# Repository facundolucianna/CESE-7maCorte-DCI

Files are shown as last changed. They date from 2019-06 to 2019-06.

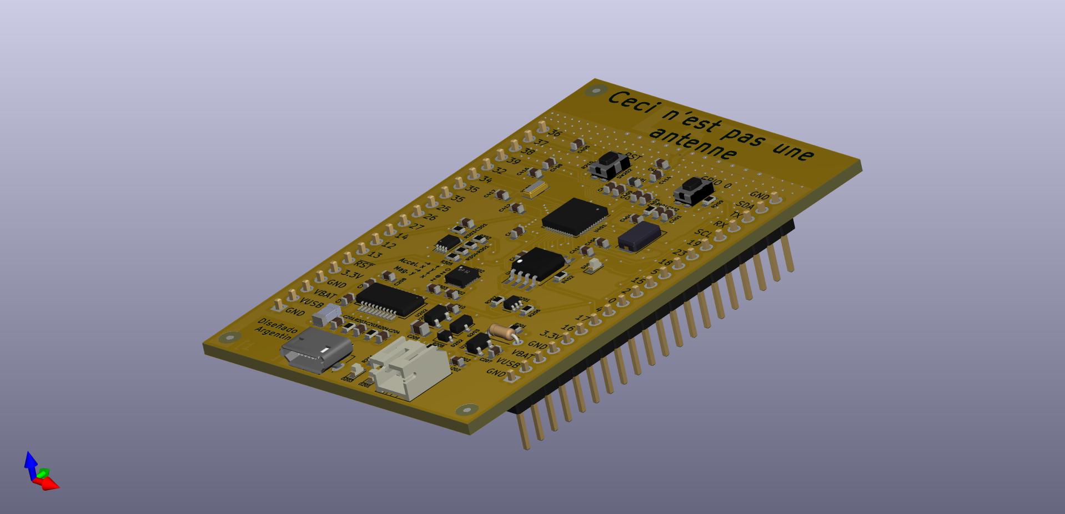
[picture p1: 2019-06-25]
3DPictures/13YellowWeirdAngle.jpg

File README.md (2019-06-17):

# CESE-7maCorte-DCI

Replica de Sparkfun ESP32 Thing. 

Basado de SparkFun ESP32 Thing (https://www.sparkfun.com/products/13907) 

Bajo Licencia Creative Commons Attributions Share-Alike 4.0 (https://creativecommons.org/licenses/by-sa/4.0/)

Modificación sin el respaldo del autor original

Atención:

Este diseño de PCB y esquematico se entrega "como está" y sin niguna garantia expresa o implícita, incluyendo, sin limitación, las garantias implícitas de comercialización y aptitude para un propósito particular.

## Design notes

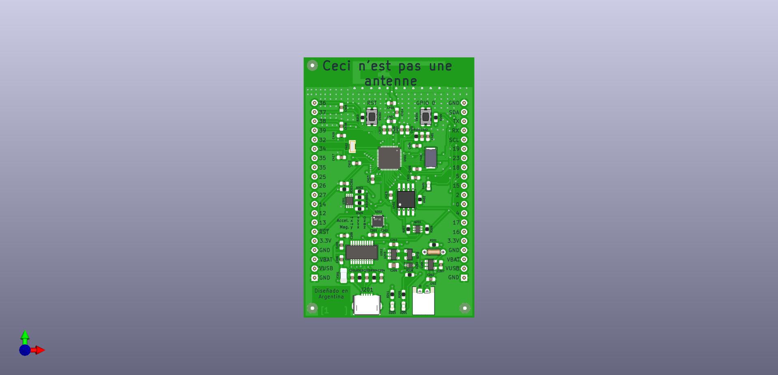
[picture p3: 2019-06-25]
3DPictures/07CheapVersionFront.jpg

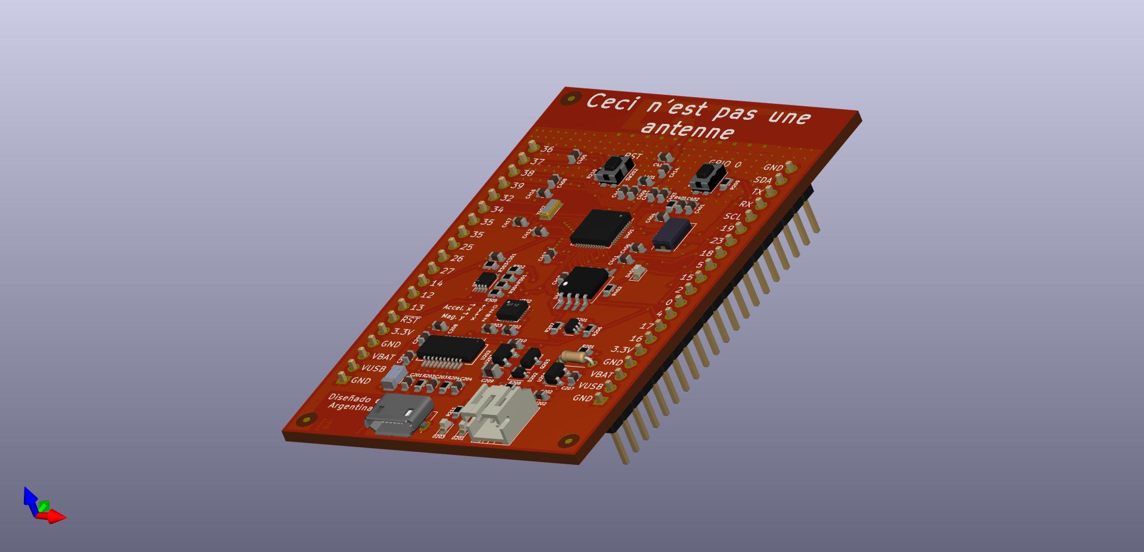
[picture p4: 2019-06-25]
3DPictures/11SparfunVersionWeirdAngle.jpg

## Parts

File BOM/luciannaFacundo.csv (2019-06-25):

Id | Designator | Package | Quantity | Designation | Supplier and ref
1 | A401 | SWRU120B | 1 | SWRU120B
2 | FID106,FID105,FID104,FID103,FID102,FID101 | Fiducial_1mm_Mask3mm | 6 | Fiducial
3 | U401 | QFN-48-1EP_6x6mm_P0.4mm_EP4.3x4.3mm | 1 | ESP32
4 | C210 | C_0603_1608Metric | 1 | 2.2uF
5 | Q203 | SOT-23 | 1 | 2.5A/30V
6 | Y402 | Crystal_SMD_3215-2Pin_3.2x1.5mm | 1 | 32.768kHz
7 | U301 | VSSOP-8_2.3x2mm_P0.5mm | 1 | PCA9306
8 | U203 | SOT-23-5 | 1 | AP2112K-3.3
9 | U202 | SSOP-20_3.9x8.7mm_P0.635mm | 1 | FT231XS
10 | U201 | SOT-23-5 | 1 | MCP73831
11 | SW202,SW201 | SW_Push_1P1T_NO_CK_KMR2 | 2 | SW_DIP_x01
12 | R402 | R_0603_1608Metric | 1 | 330
13 | R401 | R_0603_1608Metric | 1 | 20K
14 | R305,R304,R302,R301,R205 | R_0603_1608Metric | 5 | 1k
15 | R303 | R_0603_1608Metric | 1 | 200k
16 | R211 | R_0603_1608Metric | 1 | 1K
17 | R210,R209,R208,R207,R206 | R_0603_1608Metric | 5 | 10k
18 | R204,R203 | R_0603_1608Metric | 2 | 27
19 | R201 | R_0603_1608Metric | 1 | 2.0k
20 | Q201 | SOT-363_SC-70-6 | 1 | MBT3904DW1
21 | L401 | L_0603_1608Metric | 1 | 2.7nH
22 | JP401 | SolderJumper-3_P1.3mm_Bridged2Bar12_RoundedPad1.0x1.5mm | 1 | SolderJumper_3_Bridged12
23 | JP202,JP201 | SolderJumper-2_P1.3mm_Bridged2Bar_RoundedPad1.0x1.5mm | 2 | SolderJumper_2_Bridged
24 | J202 | JST_PH_S2B-PH-K_1x02_P2.00mm_Horizontal | 1 | LiPo
25 | F201 | Fuse_1206_3216Metric | 1 | 500mA
26 | D401 | LED_0603_1608Metric | 1 | BLUE
27 | D203 | LED_0603_1608Metric | 1 | RED
28 | D202 | D_SOD-323 | 1 | BAT20J
29 | D201 | LED_0603_1608Metric | 1 | YELLOW
30 | C418,C412,C411,C409,C407,C303,C302,C301,C208,C205,C201 | C_0603_1608Metric | 11 | 100nF
31 | C417,C416 | C_0603_1608Metric | 2 | 15pF
32 | C415 | C_0603_1608Metric | 1 | 2.4pF
33 | C414 | C_0603_1608Metric | 1 | 5.6pF
34 | C413 | C_0603_1608Metric | 1 | 1.0uF
35 | C410 | C_0603_1608Metric | 1 | 10uF
36 | C408,C405 | C_0603_1608Metric | 2 | 270pF
37 | C406,C404 | C_0603_1608Metric | 2 | 10pF
38 | C403 | C_0603_1608Metric | 1 | 100pF
39 | C402 | C_0603_1608Metric | 1 | 3nF
40 | C401 | C_0603_1608Metric | 1 | 10nF
41 | C209 | C_0805_2012Metric | 1 | 1.0uF
42 | C207,C206,C202 | C_0603_1608Metric | 3 | 4.7uF
43 | C204,C203 | C_0603_1608Metric | 2 | 47pF
44 | U402 | SOIC-8_5.23x5.23mm_P1.27mm | 1 | W25Q32JVSS
45 | J401,J402 | PinHeader_1x20_P2.54mm_Vertical | 2 | Conn_01x20
46 | U302 | InvenSense_QFN-24_3x3mm_P0.4mm | 1 | ICM-20948
47 | R202 | R_Axial_DIN0204_L3.6mm_D1.6mm_P5.08mm_Horizontal | 1 | DNP
48 | J201 | USB_Micro-B_GCT_USB3076-30-A | 1 | USB_B_Micro
49 | LOGO101 | OSHW-Logo2_7.3x6mm_SilkScreen | 1 | Logo_Open_Hardware
50 | LOGO102 | KiCad-Logo2_5mm_SilkScreen | 1 | Logo_Kicad
51 | Y401 | Crystal_SMD_5032-2Pin_5.0x3.2mm | 1 | 26MHz

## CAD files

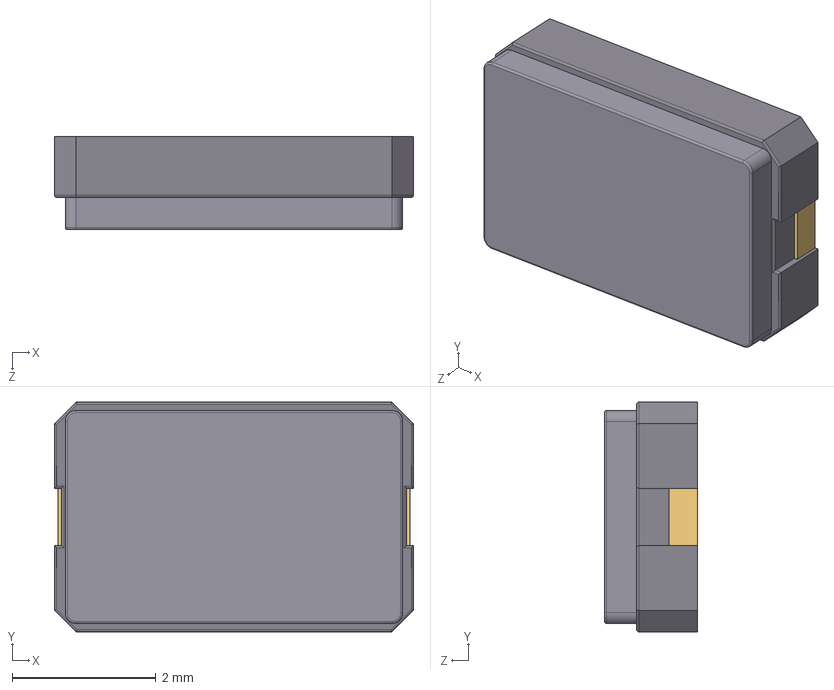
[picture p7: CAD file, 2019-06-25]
3dfootprints/User Library-ABM3-1.STEP
5.00 x 3.20 x 1.30 mm
User Library-ABM3-1_Fillet002
User Library-ABM3-1_Fillet001
User Library-ABM3-1_Pad001

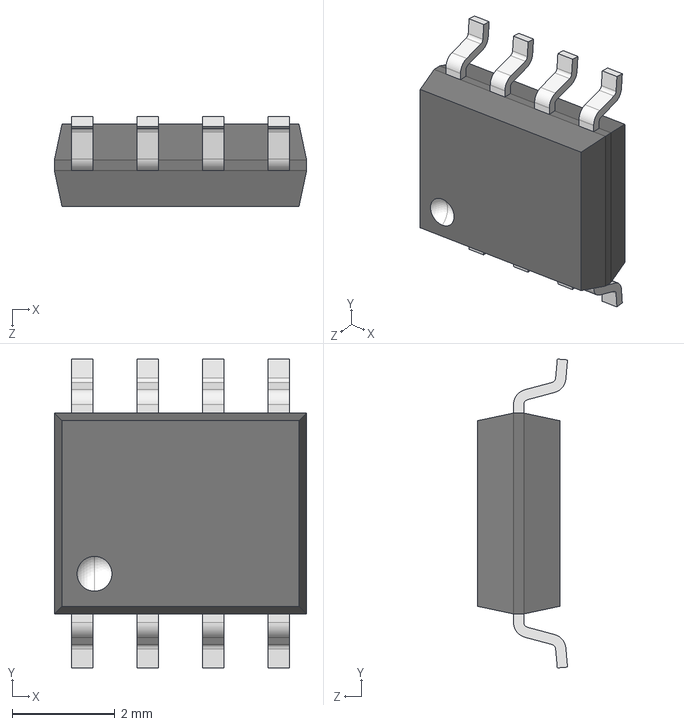
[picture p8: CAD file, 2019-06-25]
3dfootprints/User Library-SOIC-8-1.step
4.90 x 6.00 x 1.75 mm

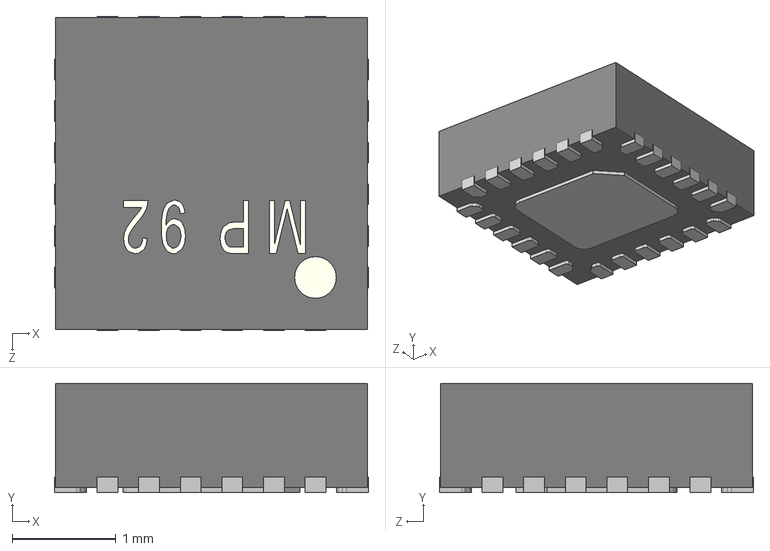
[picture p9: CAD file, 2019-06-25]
3dfootprints/User Library-MPU9250.step
3.02 x 1.05 x 3.02 mm

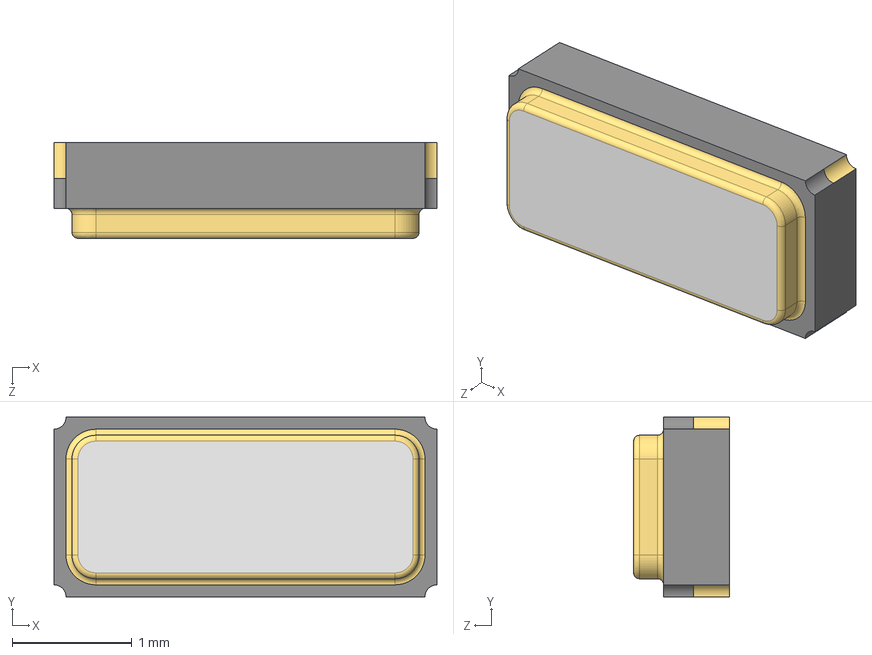
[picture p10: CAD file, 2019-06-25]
3dfootprints/User Library-NDK_NX3215SA.step
3.20 x 1.50 x 0.8 mm

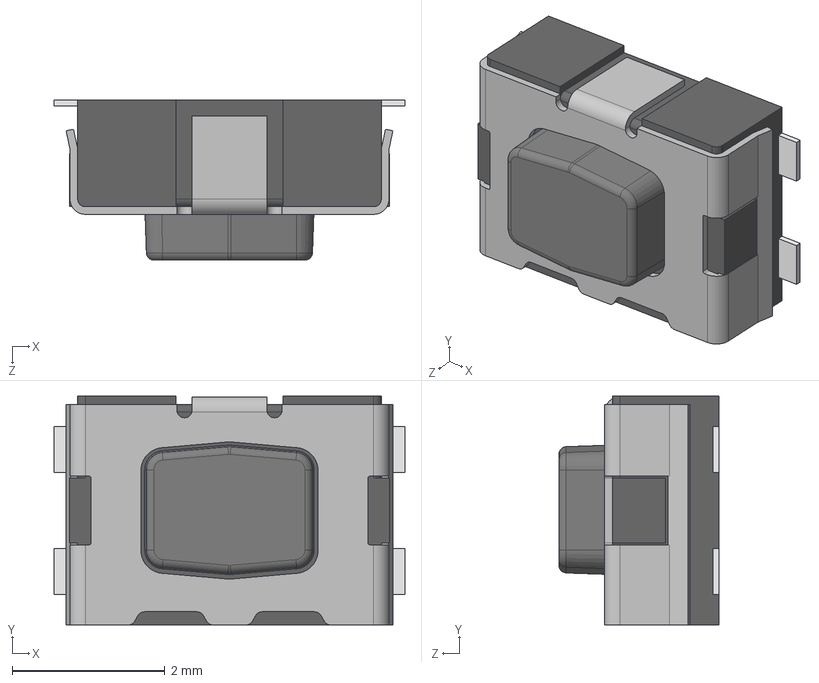
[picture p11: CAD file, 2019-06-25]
3dfootprints/User Library-Switch-CK-KMR2.STEP
4.60 x 3.00 x 2.10 mm
User Library-Switch-CK-KMR2_Button
User Library-Switch-CK-KMR2_Boitier
User Library-Switch-CK-KMR2_Tole
User Library-Switch-CK-KMR2_Pads

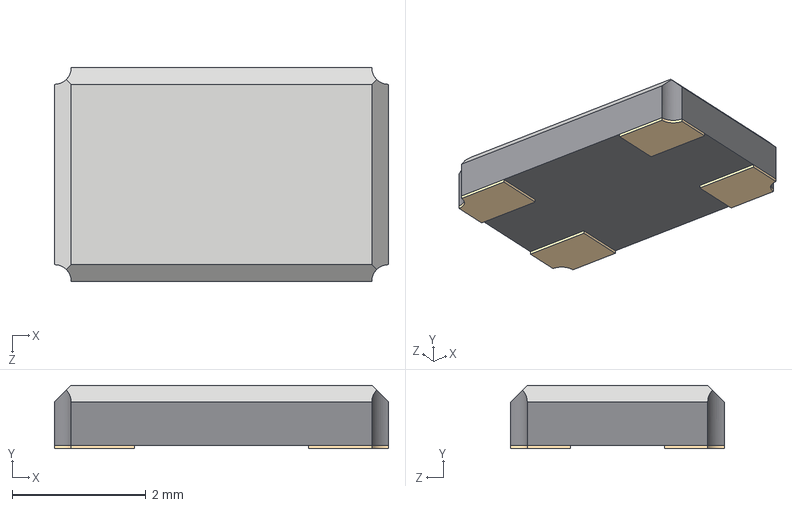
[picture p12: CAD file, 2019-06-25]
3dfootprints/User Library-Crystal.step
5.00 x 0.95 x 3.20 mm

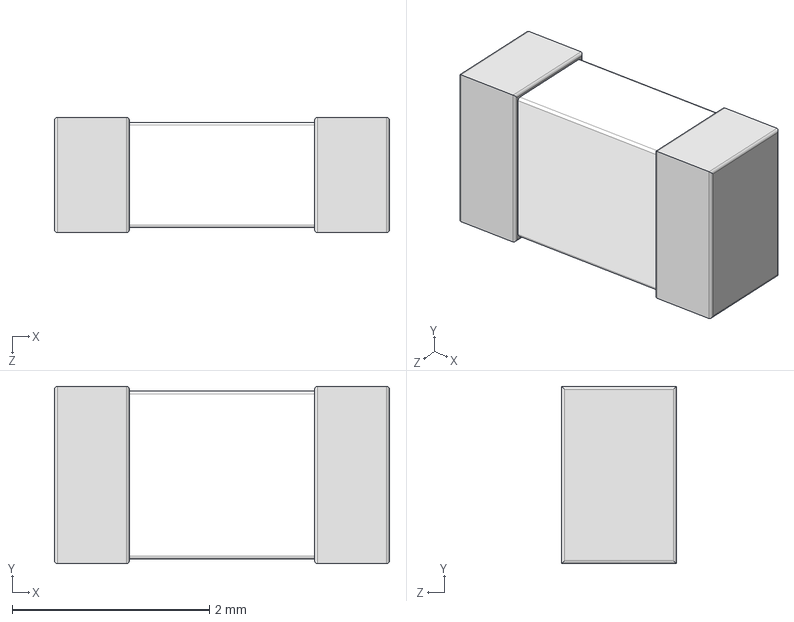
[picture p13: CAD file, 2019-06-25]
3dfootprints/User Library-Fuse_1206.step
3.40 x 1.80 x 1.17 mm

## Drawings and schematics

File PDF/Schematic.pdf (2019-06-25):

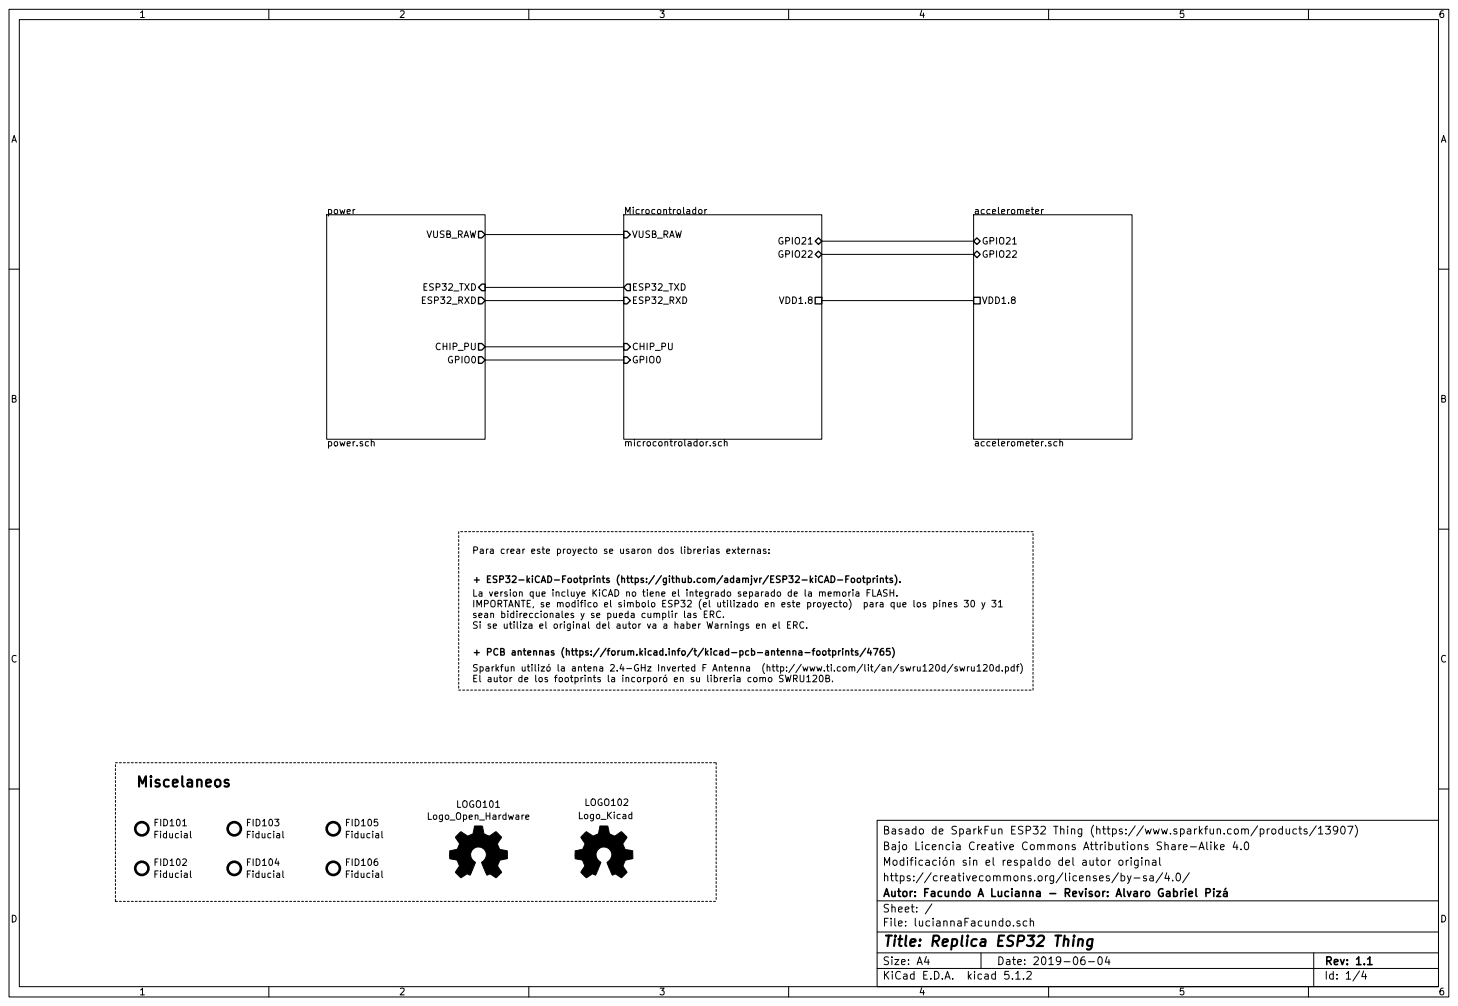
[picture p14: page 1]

accelerometer accelerometer.sch GPIO21 GPIO22 VDD1.8 Microcontrolador microcontrolador.sch CHIP_PU

+ ESP32-kiCAD-Footprints (https://github.com/adamjvr/ESP32-kiCAD-Footprints).
La version que incluye KiCAD no tiene el integrado separado de la memoria FLASH.
IMPORTANTE, se modifico el simbolo ESP32 (el utilizado en este proyecto) para que los pines 30 y 31
sean bidireccionales y se pueda cumplir las ERC.
Si se utiliza el original del autor va a haber Warnings en el ERC.

+ PCB antennas (https://forum.kicad.info/t/kicad-pcb-antenna-footprints/4765) FID104 Fiducial FID103 Fiducial FID101 Fiducial FID102 Fiducial Miscelaneos

Sparkfun utilizó la antena 2.4-GHz Inverted F Antenna (http://www.ti.com/lit/an/swru120d/swru120d.pdf)
El autor de los footprints la incorporó en su libreria como SWRU120B.

Basado de SparkFun ESP32 Thing (https://www.sparkfun.com/products/13907)
Bajo Licencia Creative Commons Attributions Share-Alike 4.0
Modificación sin el respaldo del autor original
https://creativecommons.org/licenses/by-sa/4.0/
File: luciannaFacundo.sch Sheet: / Autor: Facundo A Lucianna - Revisor: Alvaro Gabriel Pizá

Id: 1/4 Title: Replica ESP32 Thing

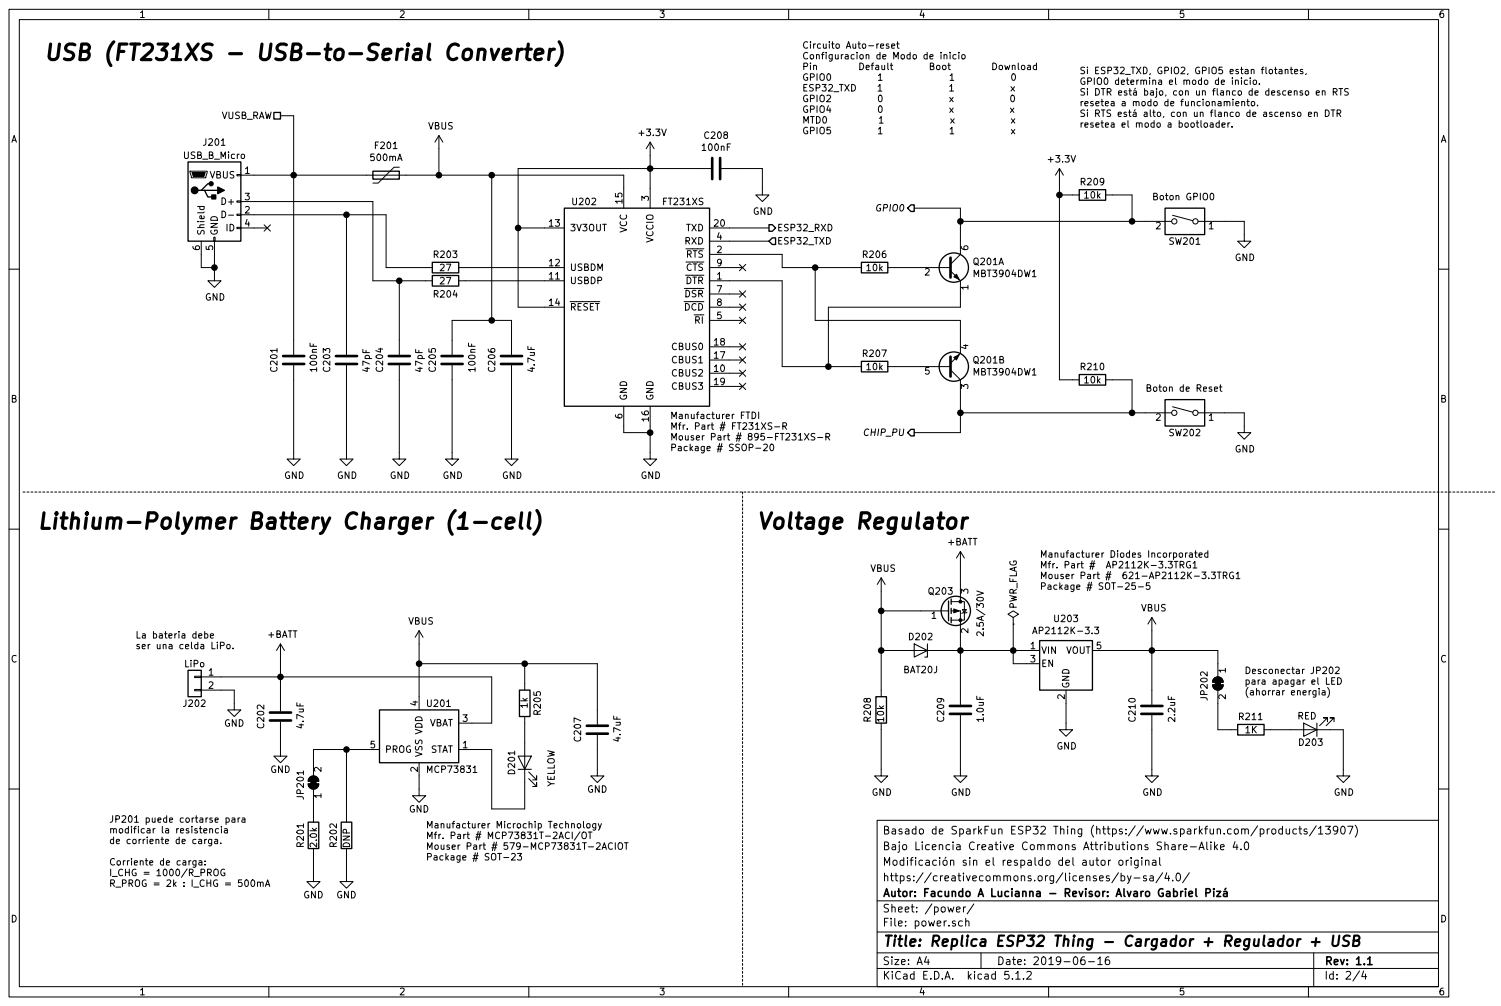
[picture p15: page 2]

USB (FT231XS - USB-to-Serial Converter)

10k Si ESP32_TXD, GPIO2, GPIO5 estan flotantes, GPIO0 determina el modo de inicio. Si DTR está bajo, con un flanco de descenso en RTS

resetea a modo de funcionamiento. Si RTS está alto, con un flanco de ascenso en DTR

Boton GPIO0 Boton de Reset 1
CHIP_PU GPIO0 R206

Manufacturer Diodes Incorporated Mfr. Part # AP2112K-3.3TRG1 Mouser Part # 621-AP2112K-3.3TRG1 Package # SOT-25-5

JP201 puede cortarse para modificar la resistencia

Manufacturer Microchip Technology Mfr. Part # MCP73831T-2ACI/OT Mouser Part # 579-MCP73831T-2ACIOT Package # SOT-23

Basado de SparkFun ESP32 Thing (https://www.sparkfun.com/products/13907)
Bajo Licencia Creative Commons Attributions Share-Alike 4.0
Modificación sin el respaldo del autor original
https://creativecommons.org/licenses/by-sa/4.0/
Autor: Facundo A Lucianna - Revisor: Alvaro Gabriel Pizá
Sheet: /power/
File: power.sch
Id: 2/4 Title: Replica ESP32 Thing - Cargador + Regulador + USB

de corriente de carga.

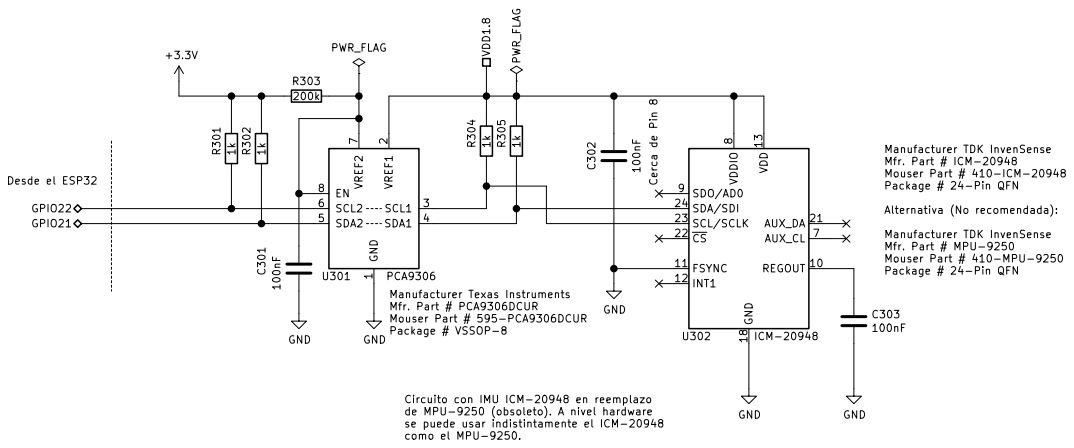
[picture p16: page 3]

7 EN 8U301 PCA9306 C301 100nF R304 1kR305 1k Cerca de Pin 8

Circuito con IMU ICM-20948 en reemplazo
de MPU-9250 (obsoleto). A nivel hardware
se puede usar indistintamente el ICM-20948

Modificación sin el respaldo del autor original
https://creativecommons.org/licenses/by-sa/4.0/
Modificacion: Agregado de IMU
Id: 3/4 Title: Replica ESP32 Thing - Inertial measurement unit File: accelerometer.sch Sheet: /accelerometer/ Autor: Facundo A Lucianna - Revisor: Alvaro Gabriel Pizá

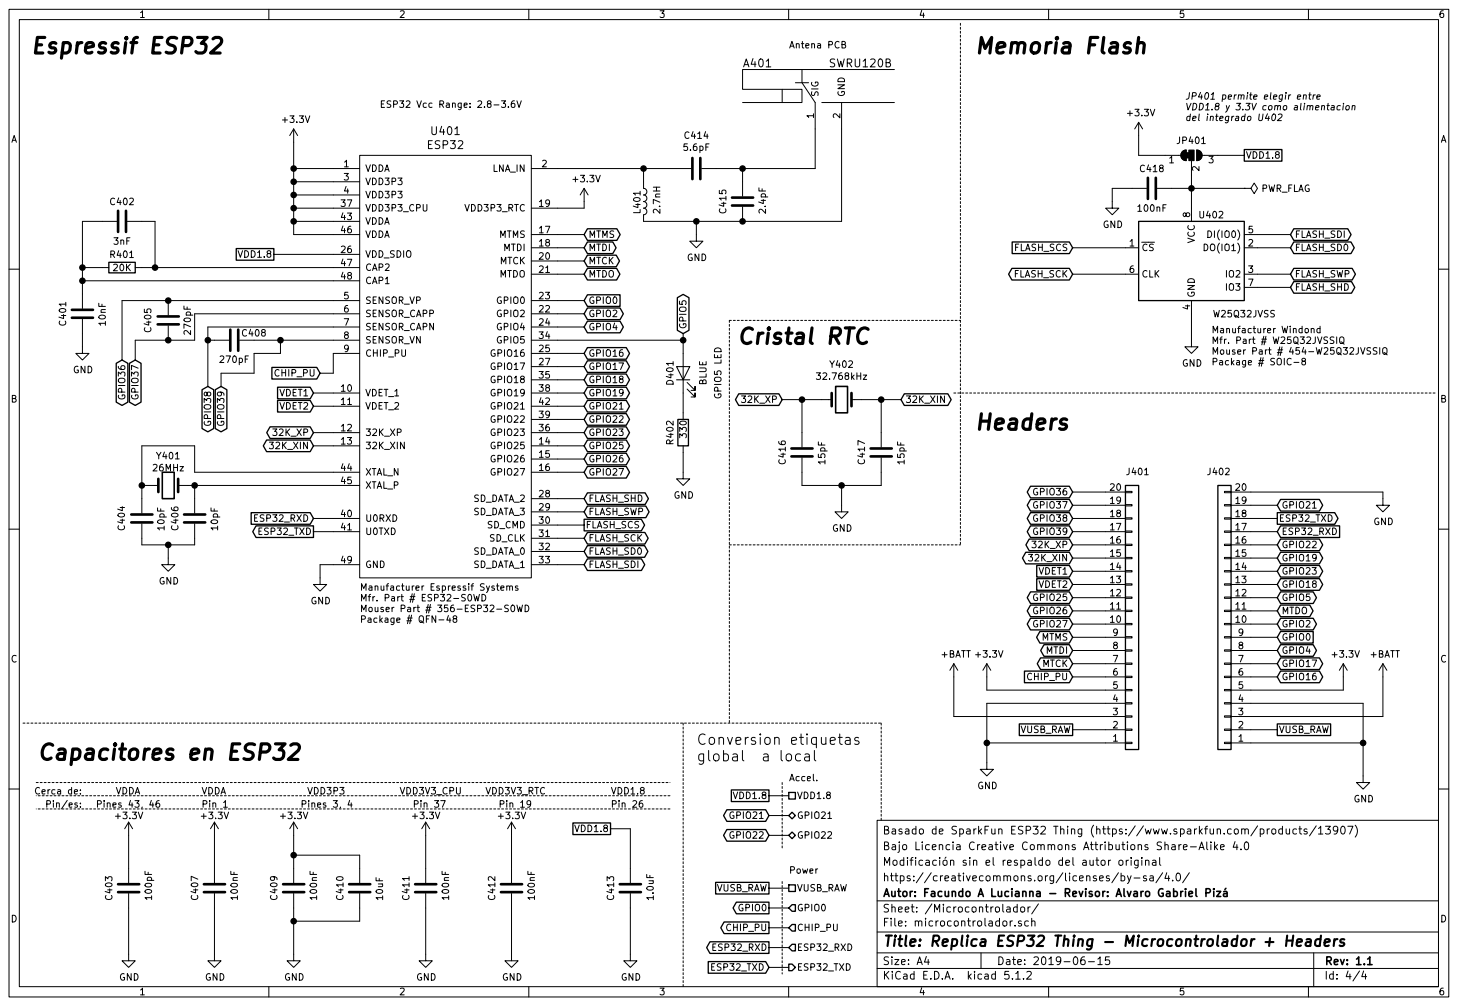
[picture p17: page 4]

Basado de SparkFun ESP32 Thing (https://www.sparkfun.com/products/13907)
Bajo Licencia Creative Commons Attributions Share-Alike 4.0
Modificación sin el respaldo del autor original
https://creativecommons.org/licenses/by-sa/4.0/
File: microcontrolador.sch Sheet: /Microcontrolador/ Autor: Facundo A Lucianna - Revisor: Alvaro Gabriel Pizá

Id: 4/4 Title: Replica ESP32 Thing - Microcontrolador + Headers

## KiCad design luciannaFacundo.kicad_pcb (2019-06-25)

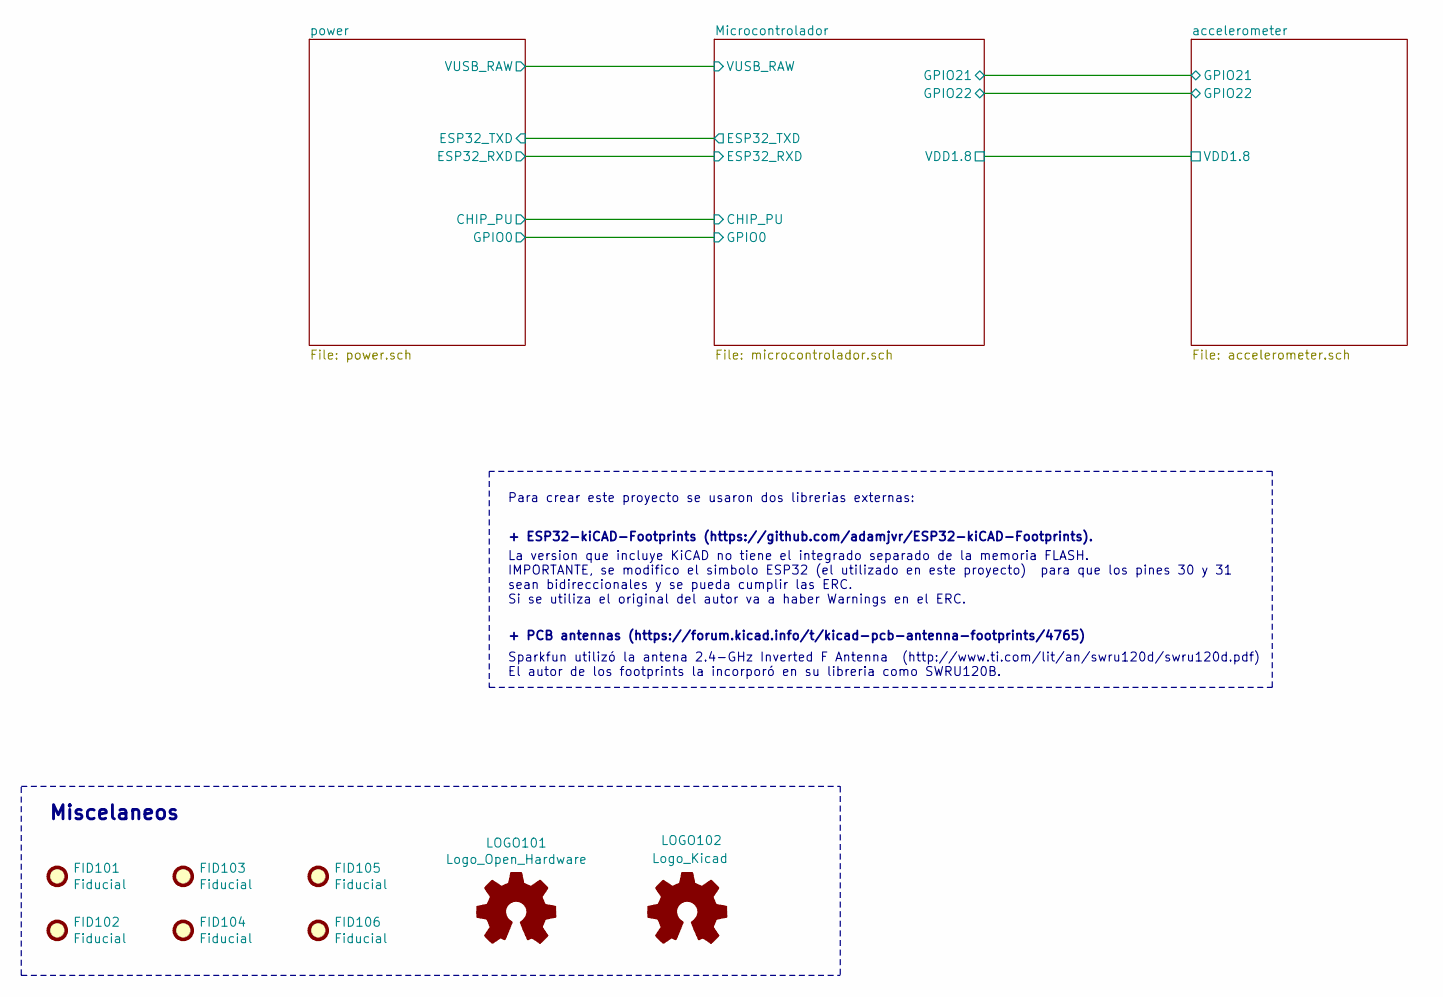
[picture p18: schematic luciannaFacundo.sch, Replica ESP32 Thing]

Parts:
FID101, FID102, FID103, FID104, FID105, FID106: Fiducial; Fiducial_1mm_Mask3mm
LOGO101: Logo_Open_Hardware; OSHW-Logo2_7.3x6mm_SilkScreen
LOGO102: Logo_Kicad; KiCad-Logo2_5mm_SilkScreen

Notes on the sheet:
Para crear este proyecto se usaron dos librerias externas: La version que incluye KiCAD no tiene el integrado separado de la memoria FLASH. IMPORTANTE, se modifico el simbolo ESP32 (el utilizado en este proyecto) para que los pines 30 y 31 sean bidireccionales y se pueda cumplir las ERC. Si se util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
+ ESP32-kiCAD-Footprints (https://github.com/adamjvr/ESP32-kiCAD-Footprints).
+ PCB antennas (https://forum.kicad.info/t/kicad-pcb-antenna-footprints/4765)
Miscelaneos

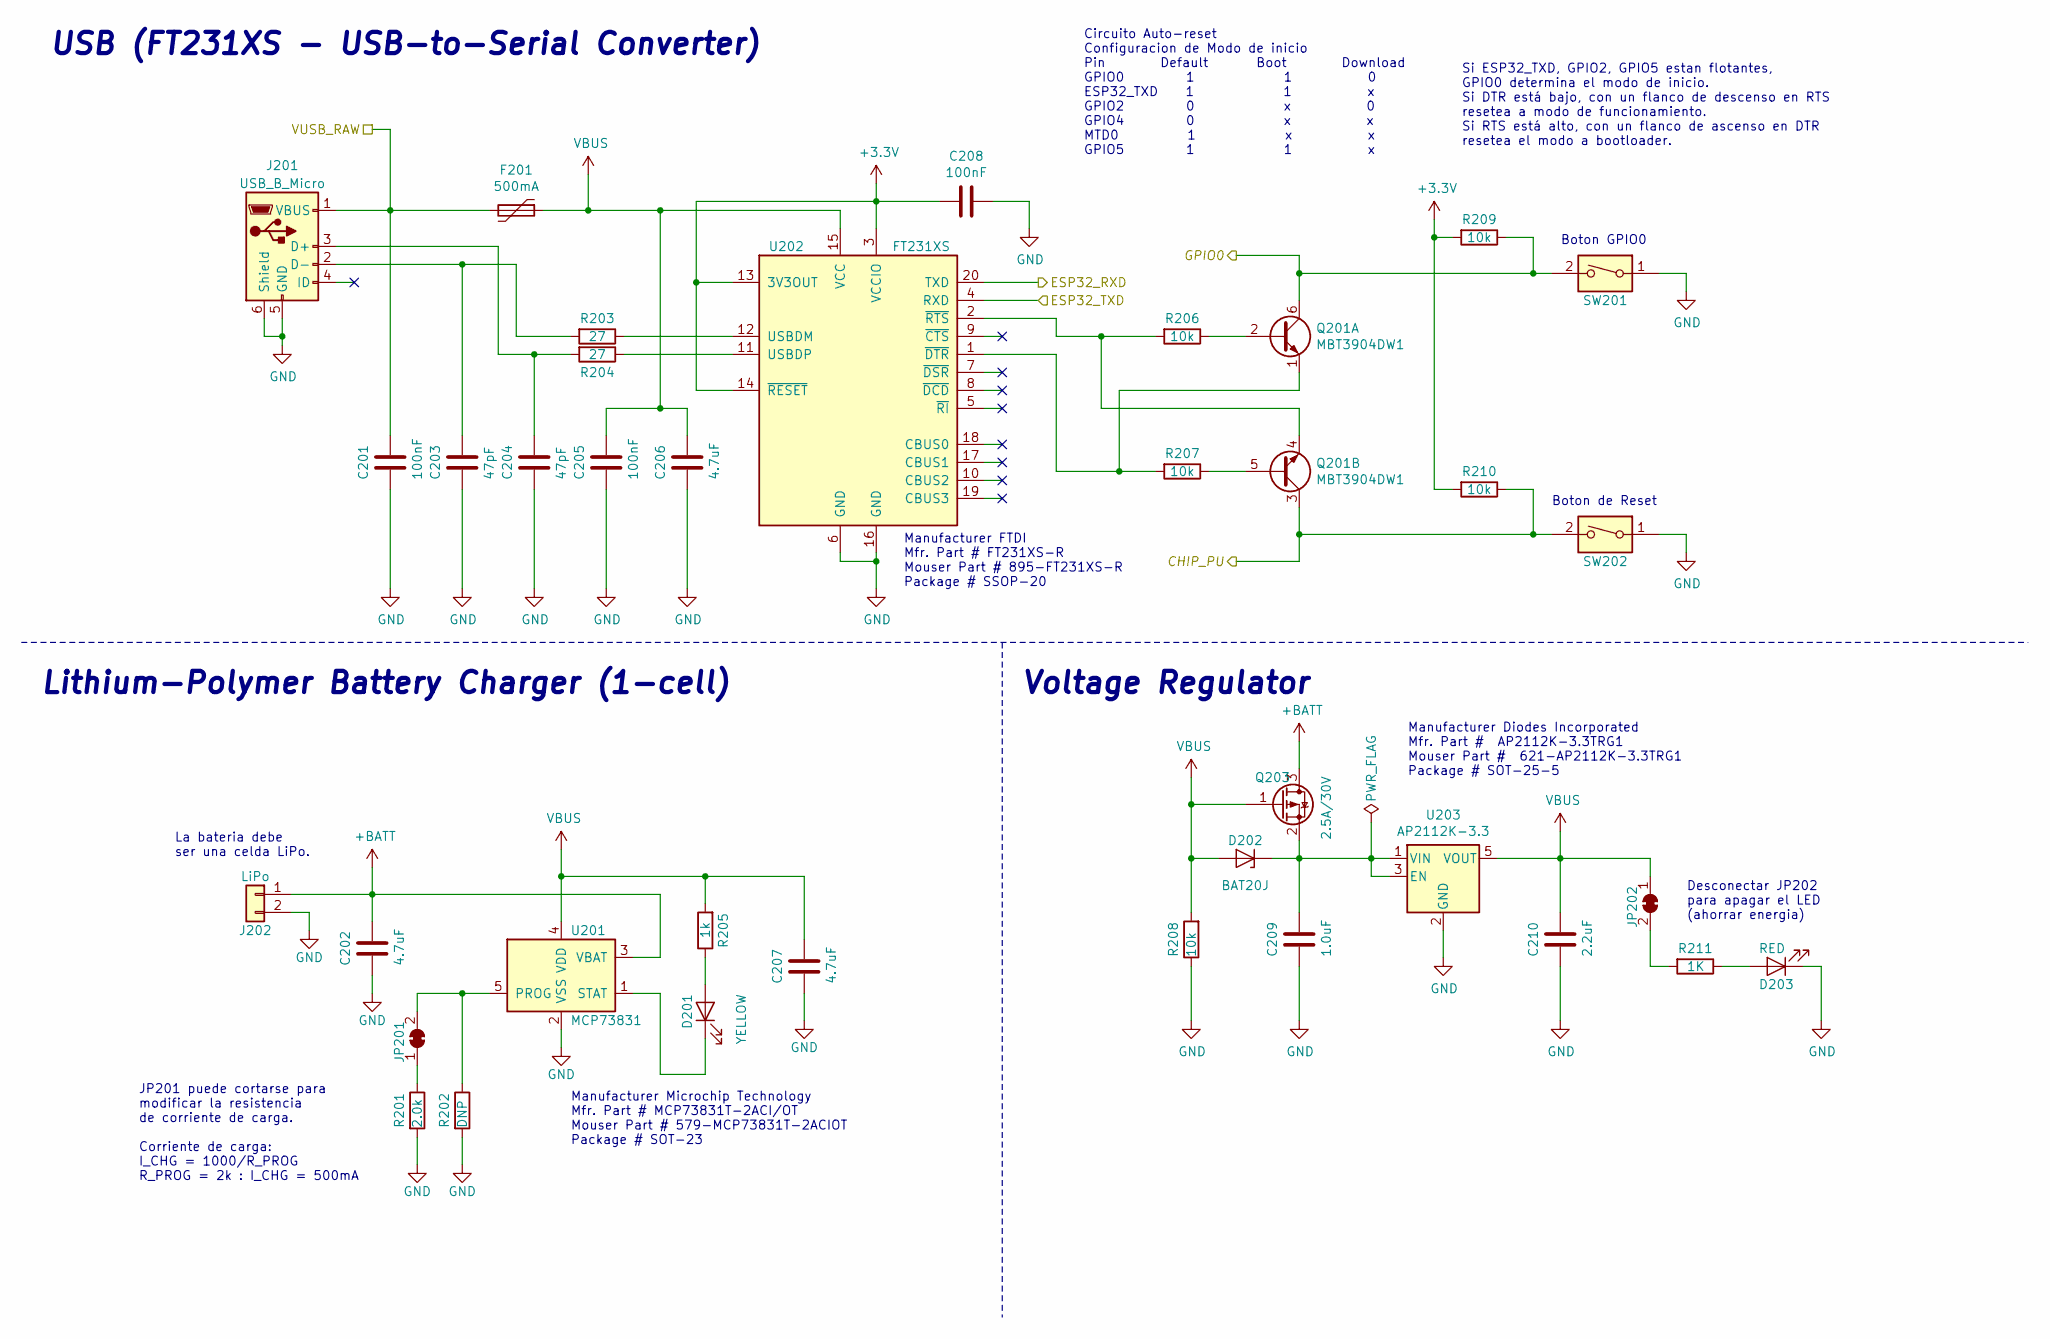
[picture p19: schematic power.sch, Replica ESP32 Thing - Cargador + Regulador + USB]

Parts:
C201, C205, C208: 100nF; C_0603_1608Metric
C202, C206, C207: 4.7uF; C_0603_1608Metric
C203, C204: 47pF; C_0603_1608Metric
C209: 1.0uF; C_0805_2012Metric
C210: 2.2uF; C_0603_1608Metric
D201: YELLOW; LED_0603_1608Metric
D202: BAT20J; D_SOD-323
D203: RED; LED_0603_1608Metric
F201: 500mA; Fuse_1206_3216Metric
J201: USB_B_Micro; USB_Micro-B_GCT_USB3076-30-A
J202: LiPo; JST_PH_S2B-PH-K_1x02_P2.00mm_Horizontal
JP201, JP202: SolderJumper_2_Bridged; SolderJumper-2_P1.3mm_Bridged2Bar_RoundedPad1.0x1.5mm
Q201: MBT3904DW1; SOT-363_SC-70-6
Q203: 2.5A/30V; SOT-23
R201: 2.0k; R_0603_1608Metric
R202: DNP; R_Axial_DIN0204_L3.6mm_D1.6mm_P5.08mm_Horizontal
R203, R204: 27; R_0603_1608Metric
R205: 1k; R_0603_1608Metric
R206, R207, R208, R209, R210: 10k; R_0603_1608Metric
R211: 1K; R_0603_1608Metric
SW201, SW202: SW_DIP_x01; SW_Push_1P1T_NO_CK_KMR2
U201: MCP73831; SOT-23-5
U202: FT231XS; SSOP-20_3.9x8.7mm_P0.635mm
U203: AP2112K-3.3; SOT-23-5

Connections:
+3V3: C208.2, R209.2, R210.2, U202.3 (VCCIO), U202.13 (3V3OUT), U202.14 (~RESET); also elsewhere on the board
+BATT: C202.1, J202.1, Q203.3 (D), U201.3 (VBAT); also elsewhere on the board
CHIP_PU: Q201.3 (C2), R210.1, SW202.2; also elsewhere on the board
ESP32_RXD: U202.20 (TXD); also elsewhere on the board
ESP32_TXD: U202.4 (RXD); also elsewhere on the board
GND: C201.2, C202.2, C203.2, C204.2, C205.2, C206.2, C207.2, C208.1, C209.2, C210.2, D203.1 (K), J201.5 (GND), J201.6 (Shield), J202.2, R201.2, R202.2, R208.1, SW201.1, SW202.1, U201.2 (VSS), U202.6 (GND), U202.16 (GND), U203.2 (GND); also elsewhere on the board
GPIO0: Q201.6 (C1), R209.1, SW201.2; also elsewhere on the board
unnamed: C203.1, J201.2 (D-), R203.2
unnamed: C204.1, J201.3 (D+), R204.2
unnamed: C209.1, D202.1 (K), Q203.2 (S), U203.1 (VIN), U203.3 (EN)
unnamed: D201.1 (K), U201.1 (STAT)
unnamed: D201.2 (A), R205.1
unnamed: D203.2 (A), R211.1
unnamed: JP201.1 (A), R201.1
unnamed: JP201.2 (B), R202.1, U201.5 (PROG)
unnamed: JP202.2 (B), R211.2
unnamed: Q201.1 (E1), R207.2, U202.1 (~DTR)
unnamed: Q201.2 (B1), R206.1
unnamed: Q201.4 (E2), R206.2, U202.2 (~RTS)
unnamed: Q201.5 (B2), R207.1
unnamed: R203.1, U202.12 (USBDM)
unnamed: R204.1, U202.11 (USBDP)
VBUS: C205.1, C206.1, C207.1, C210.1, D202.2 (A), F201.1, JP202.1 (A), Q203.1 (G), R205.2, R208.2, U201.4 (VDD), U202.15 (VCC), U203.5 (VOUT)
VUSB_RAW: C201.1, F201.2, J201.1 (VBUS); also elsewhere on the board

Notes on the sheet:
Circuito Auto-reset Configuracion de Modo de inicio Pin Default Boot Download GPIO0 1 1 0 ESP32_TXD 1 1 x GPIO2 0 x 0 GPIO4 0 x x MTD0 1 x x GPIO5 1 1 x
La bateria debe ser una celda LiPo.
Desconectar JP202 para apagar el LED (ahorrar energia)
USB (FT231XS - USB-to-Serial Converter)
Lithium-Polymer Battery Charger (1-cell)
Voltage Regulator
Si ESP32_TXD, GPIO2, GPIO5 estan flotantes, GPIO0 determina el modo de inicio. Si DTR está bajo, con un flanco de descenso en RTS resetea a modo de funcionamiento. Si RTS está alto, con un flanco de ascenso en DTR resetea el modo a bootloader.
Boton GPIO0
Boton de Reset
JP201 puede cortarse para modificar la resistencia de corriente de carga. Corriente de carga: I_CHG = 1000/R_PROG R_PROG = 2k : I_CHG = 500mA
Manufacturer FTDI Mfr. Part # FT231XS-R Mouser Part # 895-FT231XS-R Package # SSOP-20
Manufacturer Microchip Technology Mfr. Part # MCP73831T-2ACI/OT Mouser Part # 579-MCP73831T-2ACIOT Package # SOT-23
Manufacturer Diodes Incorporated Mfr. Part # AP2112K-3.3TRG1 Mouser Part # 621-AP2112K-3.3TRG1 Package # SOT-25-5

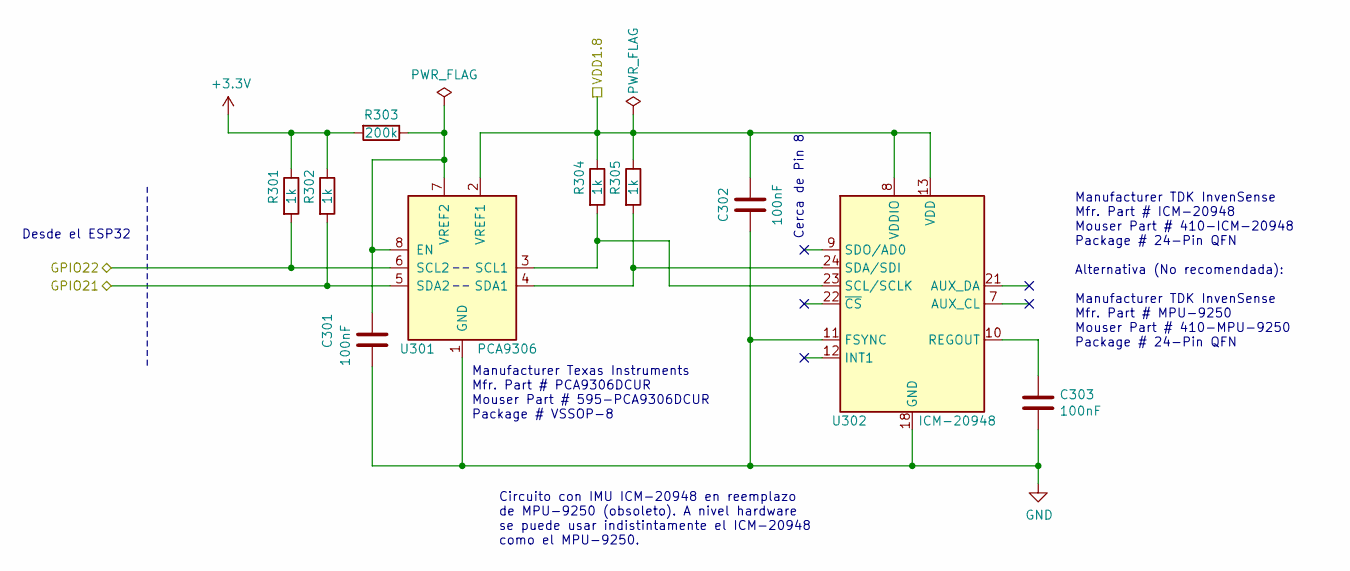
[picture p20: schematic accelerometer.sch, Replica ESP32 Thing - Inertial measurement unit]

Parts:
C301, C302, C303: 100nF; C_0603_1608Metric
R301, R302, R304, R305: 1k; R_0603_1608Metric
R303: 200k; R_0603_1608Metric
U301: PCA9306; VSSOP-8_2.3x2mm_P0.5mm
U302: ICM-20948; InvenSense_QFN-24_3x3mm_P0.4mm

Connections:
+3V3: R301.1, R302.1, R303.2; also elsewhere on the board
GND: C301.2, C302.2, C303.2, U301.1 (GND), U302.11 (FSYNC), U302.18 (GND), U302.20 (GND); also elsewhere on the board
GPIO21: R302.2, U301.5 (SDA2); also elsewhere on the board
GPIO22: R301.2, U301.6 (SCL2); also elsewhere on the board
unnamed: C301.1, R303.1, U301.7 (VREF2), U301.8 (EN)
unnamed: C303.1, U302.10 (REGOUT)
unnamed: R304.2, U301.3 (SCL1), U302.23 (SCL/SCLK)
unnamed: R305.2, U301.4 (SDA1), U302.24 (SDA/SDI)
VDD1.8: C302.1, R304.1, R305.1, U301.2 (VREF1), U302.8 (VDDIO), U302.13 (VDD); also elsewhere on the board

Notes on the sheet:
Cerca de Pin 8
Circuito con IMU ICM-20948 en reemplazo de MPU-9250 (obsoleto). A nivel hardware se puede usar indistintamente el ICM-20948 como el MPU-9250.
Desde el ESP32
Manufacturer Texas Instruments Mfr. Part # PCA9306DCUR Mouser Part # 595-PCA9306DCUR Package # VSSOP-8
Manufacturer TDK InvenSense Mfr. Part # ICM-20948 Mouser Part # 410-ICM-20948 Package # 24-Pin QFN Alternativa (No recomendada): Manufacturer TDK InvenSense Mfr. Part # MPU-9250 Mouser Part # 410-MPU-9250 Package # 24-Pin QFN

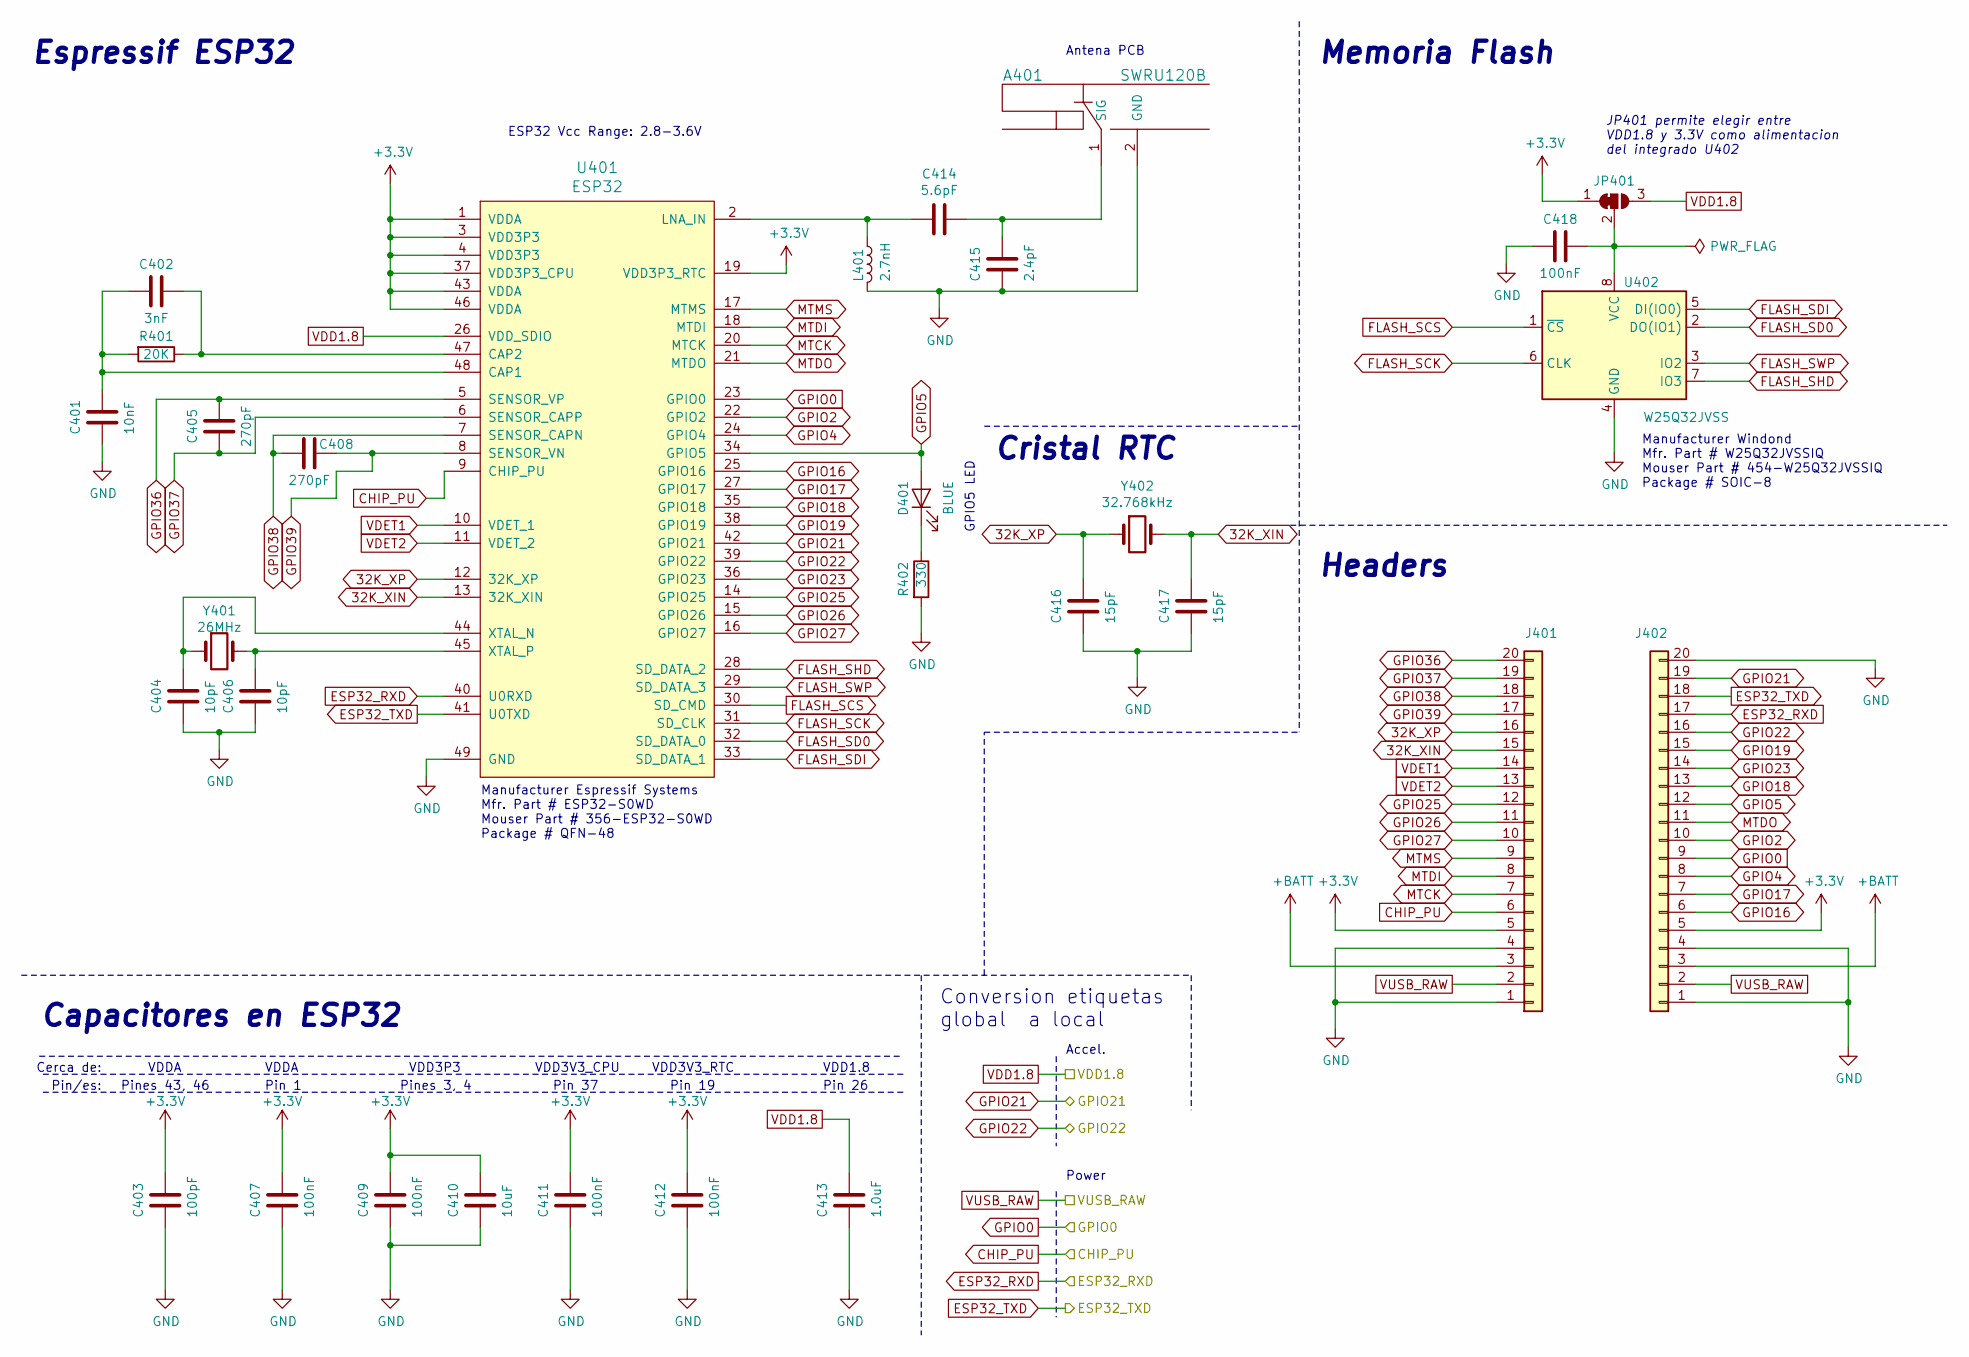
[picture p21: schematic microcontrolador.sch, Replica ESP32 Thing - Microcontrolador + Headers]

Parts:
A401: SWRU120B
C401: 10nF; C_0603_1608Metric
C402: 3nF; C_0603_1608Metric
C403: 100pF; C_0603_1608Metric
C404, C406: 10pF; C_0603_1608Metric
C405, C408: 270pF; C_0603_1608Metric
C407, C409, C411, C412, C418: 100nF; C_0603_1608Metric
C410: 10uF; C_0603_1608Metric
C413: 1.0uF; C_0603_1608Metric
C414: 5.6pF; C_0603_1608Metric
C415: 2.4pF; C_0603_1608Metric
C416, C417: 15pF; C_0603_1608Metric
D401: BLUE; LED_0603_1608Metric
J401, J402: Conn_01x20; PinHeader_1x20_P2.54mm_Vertical
JP401: SolderJumper_3_Bridged12; SolderJumper-3_P1.3mm_Bridged2Bar12_RoundedPad1.0x1.5mm
L401: 2.7nH; L_0603_1608Metric
R401: 20K; R_0603_1608Metric
R402: 330; R_0603_1608Metric
U401: ESP32; QFN-48-1EP_6x6mm_P0.4mm_EP4.3x4.3mm
U402: W25Q32JVSS; SOIC-8_5.23x5.23mm_P1.27mm
Y401: 26MHz; Crystal_SMD_5032-2Pin_5.0x3.2mm
Y402: 32.768kHz; Crystal_SMD_3215-2Pin_3.2x1.5mm

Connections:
32K_XIN: C417.1, J401.15, U401.13 (32K_XIN), Y402.2
32K_XP: C416.1, J401.16, U401.12 (32K_XP), Y402.1
+3V3: C403.1, C407.1, C409.1, C410.1, C411.1, C412.1, J401.5, J402.5, JP401.1 (A), U401.1 (VDDA), U401.3 (VDD3P3), U401.4 (VDD3P3), U401.19 (VDD3P3_RTC), U401.37 (VDD3P3_CPU), U401.43 (VDDA), U401.46 (VDDA); also elsewhere on the board
+BATT: J401.3, J402.3; also elsewhere on the board
CHIP_PU: J401.6, U401.9 (CHIP_PU); also elsewhere on the board
ESP32_RXD: J402.17, U401.40 (U0RXD); also elsewhere on the board
ESP32_TXD: J402.18, U401.41 (U0TXD); also elsewhere on the board
FLASH_SCK: U401.31 (SD_CLK), U402.6 (CLK)
FLASH_SCS: U401.30 (SD_CMD), U402.1 (~CS)
FLASH_SD0: U401.32 (SD_DATA_0), U402.2 (DO(IO1))
FLASH_SDI: U401.33 (SD_DATA_1), U402.5 (DI(IO0))
FLASH_SHD: U401.28 (SD_DATA_2), U402.7 (IO3)
FLASH_SWP: U401.29 (SD_DATA_3), U402.3 (IO2)
GND: A401.2 (GND), C401.2, C403.2, C404.1, C406.2, C407.2, C409.2, C410.2, C411.2, C412.2, C413.2, C415.2, C416.2, C417.2, C418.2, J401.1, J401.4, J402.1, J402.4, J402.20, L401.2, R402.2, U401.49 (GND), U402.4 (GND); also elsewhere on the board
GPIO0: J402.9, U401.23 (GPIO0); also elsewhere on the board
GPIO2: J402.10, U401.22 (GPIO2)
GPIO4: J402.8, U401.24 (GPIO4)
GPIO5: D401.2 (A), J402.12, U401.34 (GPIO5)
GPIO16: J402.6, U401.25 (GPIO16)
GPIO17: J402.7, U401.27 (GPIO17)
GPIO18: J402.13, U401.35 (GPIO18)
GPIO19: J402.15, U401.38 (GPIO19)
GPIO21: J402.19, U401.42 (GPIO21); also elsewhere on the board
GPIO22: J402.16, U401.39 (GPIO22); also elsewhere on the board
GPIO23: J402.14, U401.36 (GPIO23)
GPIO25: J401.12, U401.14 (GPIO25)
GPIO26: J401.11, U401.15 (GPIO26)
GPIO27: J401.10, U401.16 (GPIO27)
GPIO36: C405.2, J401.20, U401.5 (SENSOR_VP)
GPIO37: C405.1, J401.19, U401.6 (SENSOR_CAPP)
GPIO38: C408.1, J401.18, U401.7 (SENSOR_CAPN)
GPIO39: C408.2, J401.17, U401.8 (SENSOR_VN)
MTCK: J401.7, U401.20 (MTCK)
MTDI: J401.8, U401.18 (MTDI)
MTDO: J402.11, U401.21 (MTDO)
MTMS: J401.9, U401.17 (MTMS)
unnamed: A401.1 (SIG), C414.1, C415.1
unnamed: C401.1, C402.2, R401.2, U401.48 (CAP1)
unnamed: C402.1, R401.1, U401.47 (CAP2)
unnamed: C404.2, U401.44 (XTAL_N), Y401.1
unnamed: C406.1, U401.45 (XTAL_P), Y401.2
unnamed: C414.2, L401.1, U401.2 (LNA_IN)
unnamed: C418.1, JP401.2 (C), U402.8 (VCC)
unnamed: D401.1 (K), R402.1
VDD1.8: C413.1, JP401.3 (B), U401.26 (VDD_SDIO); also elsewhere on the board
VDET1: J401.14, U401.10 (VDET_1)
VDET2: J401.13, U401.11 (VDET_2)
VUSB_RAW: J401.2, J402.2; also elsewhere on the board

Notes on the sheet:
VDDA
Pin 37
VDD3V3_CPU
Pines 3, 4
VDD3P3
VDD3V3_RTC
Pin 19
Cerca de:
Pin/es:
Pin 1
Pines 43, 46
Capacitores en ESP32
Espressif ESP32
Cristal RTC
Memoria Flash
Headers
JP401 permite elegir entre VDD1.8 y 3.3V como alimentacion del integrado U402
ESP32 Vcc Range: 2.8-3.6V
GPIO5 LED
VDD1.8
Pin 26
Antena PCB
Manufacturer Espressif Systems Mfr. Part # ESP32-S0WD Mouser Part # 356-ESP32-S0WD Package # QFN-48
Manufacturer Windond Mfr. Part # W25Q32JVSSIQ Mouser Part # 454-W25Q32JVSSIQ Package # SOIC-8
Conversion etiquetas global a local
Power
Accel.

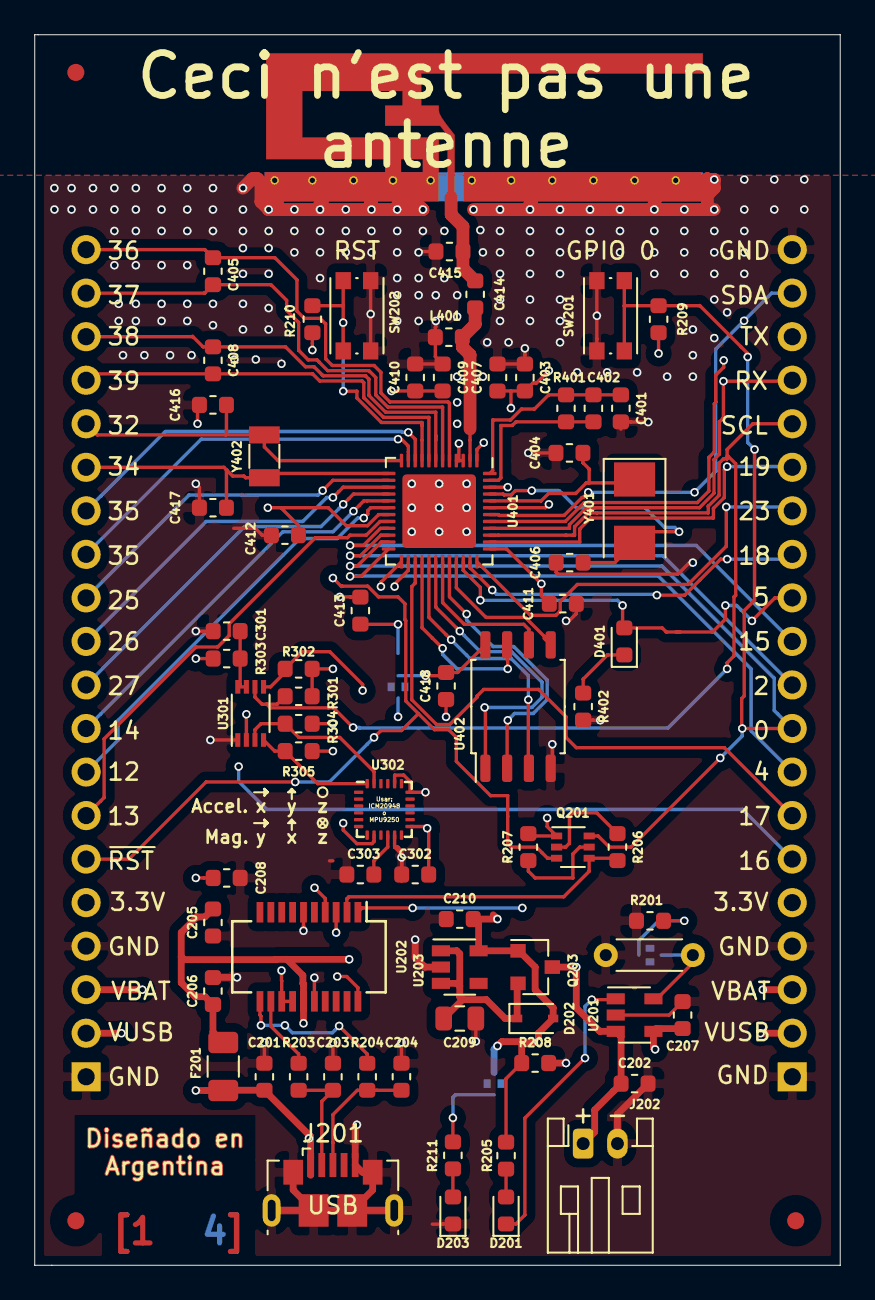
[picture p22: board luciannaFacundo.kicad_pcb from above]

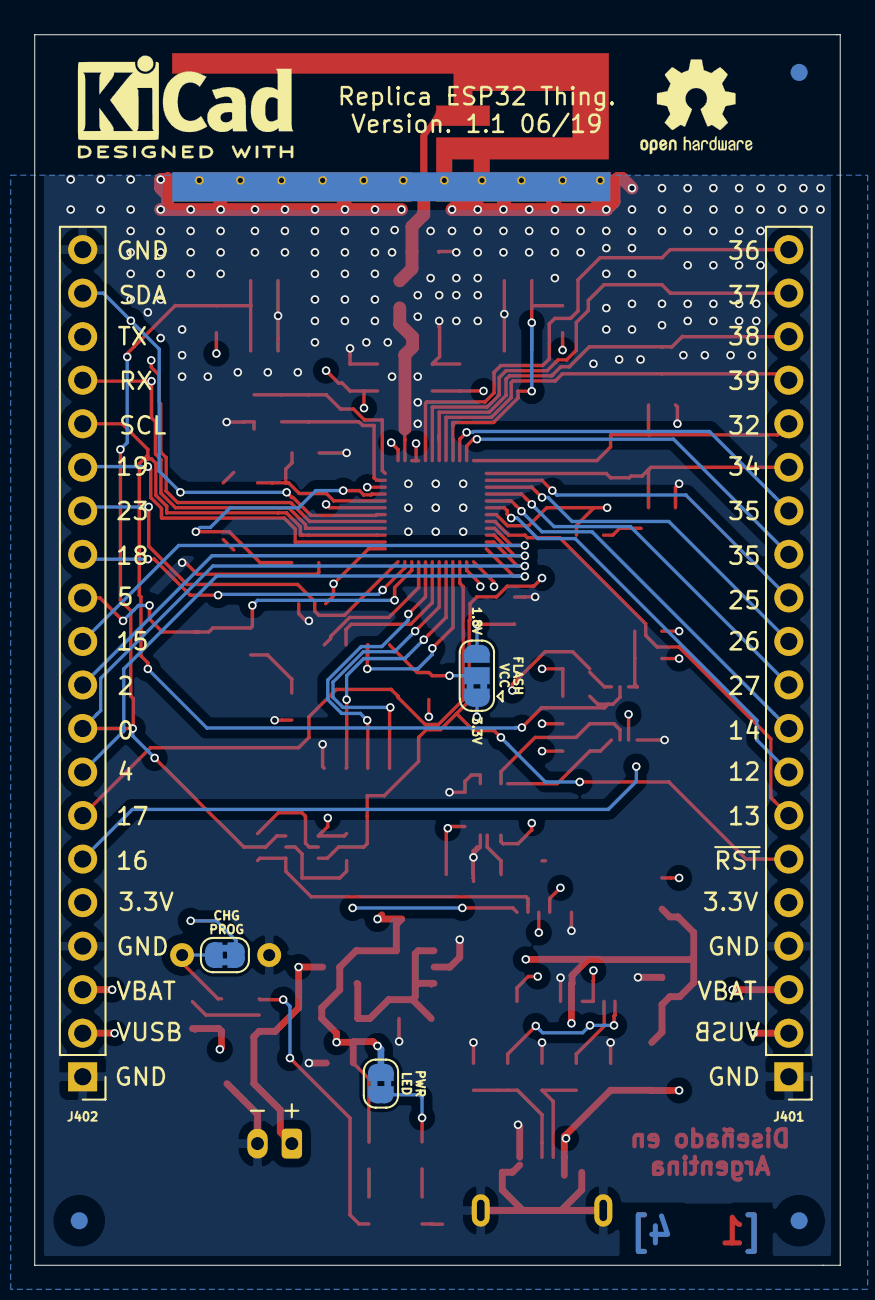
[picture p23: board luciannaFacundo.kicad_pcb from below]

Board: 4 copper layers, 47.0 x 71.8 mm, 84 parts (10 on the bottom side), 68 nets.

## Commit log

2019-06-17 PMD01 - Esquematico y footprints asignados
    [ESP32-Footprints.kicad_pcb, ESP32-Footprints.sch, accelerometer.sch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]
2019-06-17 PMD02 - Agregado de documentacion y PDF
2019-06-18 PMD03 - Creacion PCB y modelo 3D
    [accelerometer.sch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]
2019-06-25 Cambio en esquematico
    [accelerometer.sch, microcontrolador.sch]
